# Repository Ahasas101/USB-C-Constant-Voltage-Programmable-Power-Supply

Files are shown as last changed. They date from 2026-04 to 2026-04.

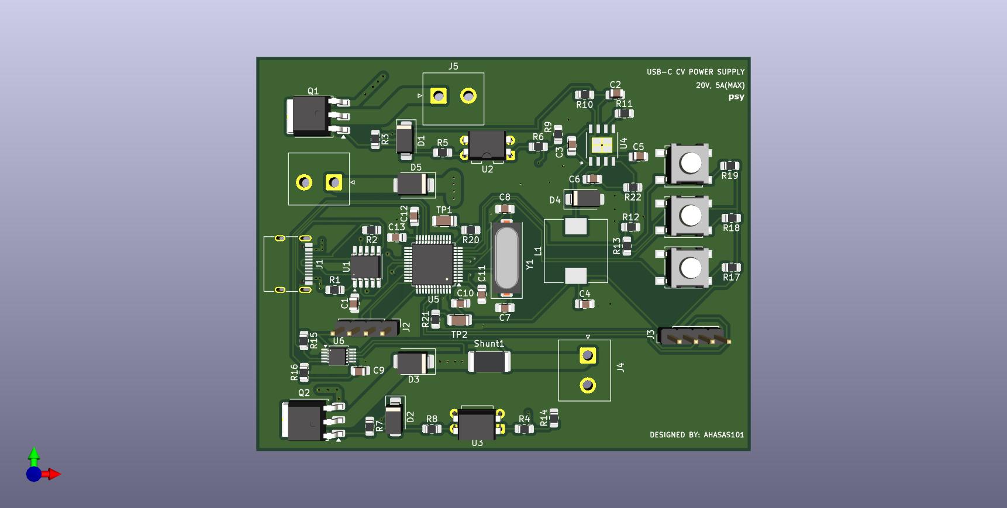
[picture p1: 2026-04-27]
Firmware/usb_ps_1/usb_ps_1.jpg

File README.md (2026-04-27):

Demonstration Video: https://www.youtube.com/shorts/JLkv3YMJE9I

100 W USB-C Power Delivery Based Programmable DC Power Supply
Overview

This project implements a compact, programmable DC power supply using USB-C Power Delivery (USB-PD). It negotiates multiple voltage levels from a USB-C charger and provides a regulated, adjustable DC output suitable for electronics development and testing.

The system is built using an STM32 microcontroller, a dedicated USB-PD controller, and a high-efficiency power conversion stage. It also includes an OLED display for real-time system feedback. Both hardware and firmware are developed from scratch .

Features
USB-C Power Delivery voltage negotiation (5V, 9V, 12V, 15V, 20V)
Programmable DC output
Dual operating modes:
Direct PD Mode (fixed voltage selection)
Adjustable Output Mode (via buck converter)
Real-time voltage and current monitoring
OLED display for live system parameters
High-efficiency power conversion
Compact and portable design
Custom PCB designed in KiCad
System Architecture
Power Path

USB-C Charger → PD Controller → Power ORing → Buck Converter → Output

Control and Monitoring

Microcontroller → INA226 Sensor → OLED Display → System Monitoring and Protection

The system architecture and block diagram are described in the project document (page 4) .

Hardware Components
STM32F030C8T6 Microcontroller
CH224K USB-PD Controller
INA226 Voltage and Current Monitor
MP1584EN Buck Converter
PMOS-based Power ORing Circuit
OLED Display (I2C)
Working Modes
1. Direct PD Mode

The PD controller negotiates and outputs fixed voltage levels directly from the USB-C charger.

2. Adjustable Output Mode

The negotiated voltage is fed into a buck converter to generate a variable DC output.

PCB Design
Designed using KiCad
Includes power stage, control circuitry, sensing modules, and display interface
High-current routing and thermal considerations implemented

Author

Ahasas Yadav

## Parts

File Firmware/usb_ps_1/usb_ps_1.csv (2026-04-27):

Reference | Qty | Value | DNP | Exclude from BOM | Exclude from Board | Footprint | Datasheet
C1 | 1 | 1uF |  |  |  | Capacitor_SMD:C_0805_2012Metric_Pad1.18x1.45mm_HandSolder | ~
C2 | 1 | 10uf |  |  |  | Capacitor_SMD:C_0805_2012Metric_Pad1.18x1.45mm_HandSolder | ~
C3 | 1 | 100nf |  |  |  | Capacitor_SMD:C_0805_2012Metric_Pad1.18x1.45mm_HandSolder | ~
C4 | 1 | 22uf |  |  |  | Capacitor_SMD:C_0805_2012Metric_Pad1.18x1.45mm_HandSolder | ~
C5 | 1 | NS |  |  |  | Capacitor_SMD:C_0805_2012Metric_Pad1.18x1.45mm_HandSolder | ~
C6 | 1 | 220pf |  |  |  | Capacitor_SMD:C_0805_2012Metric_Pad1.18x1.45mm_HandSolder | ~
C7,C8 | 2 | 18pf |  |  |  | Capacitor_SMD:C_0805_2012Metric_Pad1.18x1.45mm_HandSolder | ~
C9,C10,C11,C12,C13 | 5 | 0.1uf |  |  |  | Capacitor_SMD:C_0805_2012Metric_Pad1.18x1.45mm_HandSolder | ~
D1,D2 | 2 | 12V |  |  |  | Diode_SMD:D_SMA | ~
D3,D5 | 2 | SS10100B |  |  |  | Diode_SMD:D_SMB | ~
D4 | 1 | SS34 |  |  |  | Diode_SMD:D_SMA | ~
J1 | 1 | USB_C_Receptacle_USB2.0_16P |  |  |  | Connector_USB:USB_C_Receptacle_G-Switch_GT-USB-7010ASV | https://www.usb.org/sites/default/files/documents/usb_type-c.zip
J2 | 1 | SWD |  |  |  | Connector_PinHeader_2.54mm:PinHeader_1x04_P2.54mm_Vertical | ~
J3 | 1 | OLED |  |  |  | Connector_PinHeader_2.54mm:PinHeader_1x04_P2.54mm_Vertical | ~
J4 | 1 | O/P |  |  |  | Connector_JST:JST_NV_B02P-NV_1x02_P5.00mm_Vertical | ~
J5 | 1 | Bout |  |  |  | Connector_JST:JST_NV_B02P-NV_1x02_P5.00mm_Vertical | ~
J6 | 1 | Bin |  |  |  | Connector_JST:JST_NV_B02P-NV_1x02_P5.00mm_Vertical | ~
L1 | 1 | 10uH |  |  |  | Inductor_SMD:L_10.4x10.4_H4.8 | ~
Q1,Q2 | 2 | Q_PMOS_GDS |  |  |  | Package_TO_SOT_SMD:TO-252-3_TabPin2 | ~
R1 | 1 | 1K |  |  |  | Resistor_SMD:R_0805_2012Metric_Pad1.20x1.40mm_HandSolder | ~
R2,R20,R21 | 3 | 10K |  |  |  | Resistor_SMD:R_0805_2012Metric_Pad1.20x1.40mm_HandSolder | ~
R3,R7,R10 | 3 | 100K |  |  |  | Resistor_SMD:R_0805_2012Metric_Pad1.20x1.40mm_HandSolder | ~
R4,R6 | 2 | 470 |  |  |  | Resistor_SMD:R_0805_2012Metric_Pad1.20x1.40mm_HandSolder | ~
R5,R8 | 2 | 150 |  |  |  | Resistor_SMD:R_0805_2012Metric_Pad1.20x1.40mm_HandSolder | ~
R9,R14 | 2 | 47K |  |  |  | Resistor_SMD:R_0805_2012Metric_Pad1.20x1.40mm_HandSolder | ~
R11 | 1 | 200K |  |  |  | Resistor_SMD:R_0805_2012Metric_Pad1.20x1.40mm_HandSolder | ~
R12 | 1 | 40.2K |  |  |  | Resistor_SMD:R_0805_2012Metric_Pad1.20x1.40mm_HandSolder | ~
R13 | 1 | 124K |  |  |  | Resistor_SMD:R_0805_2012Metric_Pad1.20x1.40mm_HandSolder | ~
R15,R16,R17,R18,R19 | 5 | 4.7K |  |  |  | Resistor_SMD:R_0805_2012Metric_Pad1.20x1.40mm_HandSolder | ~
R22 | 1 | 68.1K |  |  |  | Resistor_SMD:R_0805_2012Metric_Pad1.20x1.40mm_HandSolder | ~
Shunt1 | 1 | 0.01 |  |  |  | Resistor_SMD:R_2512_6332Metric | ~
SW1 | 1 | OnOff |  |  |  | Button_Switch_SMD:SW_SPST_B3S-1000 | ~
SW2 | 1 | Mode |  |  |  | Button_Switch_SMD:SW_SPST_B3S-1000 | ~
SW3 | 1 | Level |  |  |  | Button_Switch_SMD:SW_SPST_B3S-1000 | ~
TP1 | 1 | Rst |  |  |  | Capacitor_SMD:C_1206_3216Metric | ~
TP2 | 1 | Boot |  |  |  | Capacitor_SMD:C_1206_3216Metric | ~
U1 | 1 | CH224K |  |  |  | Package_SO:SSOP-10-1EP_3.9x4.9mm_P1mm_EP2.1x3.3mm | https://www.wch.cn/downloads/file/301.html
U2,U3 | 2 | EL817 |  |  |  | Package_DIP:DIP-4_W7.62mm | http://www.everlight.com/file/ProductFile/EL817.pdf
U4 | 1 | MP1584EN-LF-P |  |  |  | footprints:SOIC8E_MPS_MNP | https://www.monolithicpower.com/en/documentview/productdocument/index/version/2/document_type/Datasheet/lang/en/sku/MP1584EN-LF-Z
U5 | 1 | STM32F030C8Tx |  |  |  | Package_QFP:LQFP-48_7x7mm_P0.5mm | https://www.st.com/resource/en/datasheet/stm32f030c8.pdf
U6 | 1 | INA226 |  |  |  | Package_SO:VSSOP-10_3x3mm_P0.5mm | http://www.ti.com/lit/ds/symlink/ina226.pdf
Y1 | 1 | 8MHz |  |  |  | Crystal:Crystal_SMD_HC49-SD | ~

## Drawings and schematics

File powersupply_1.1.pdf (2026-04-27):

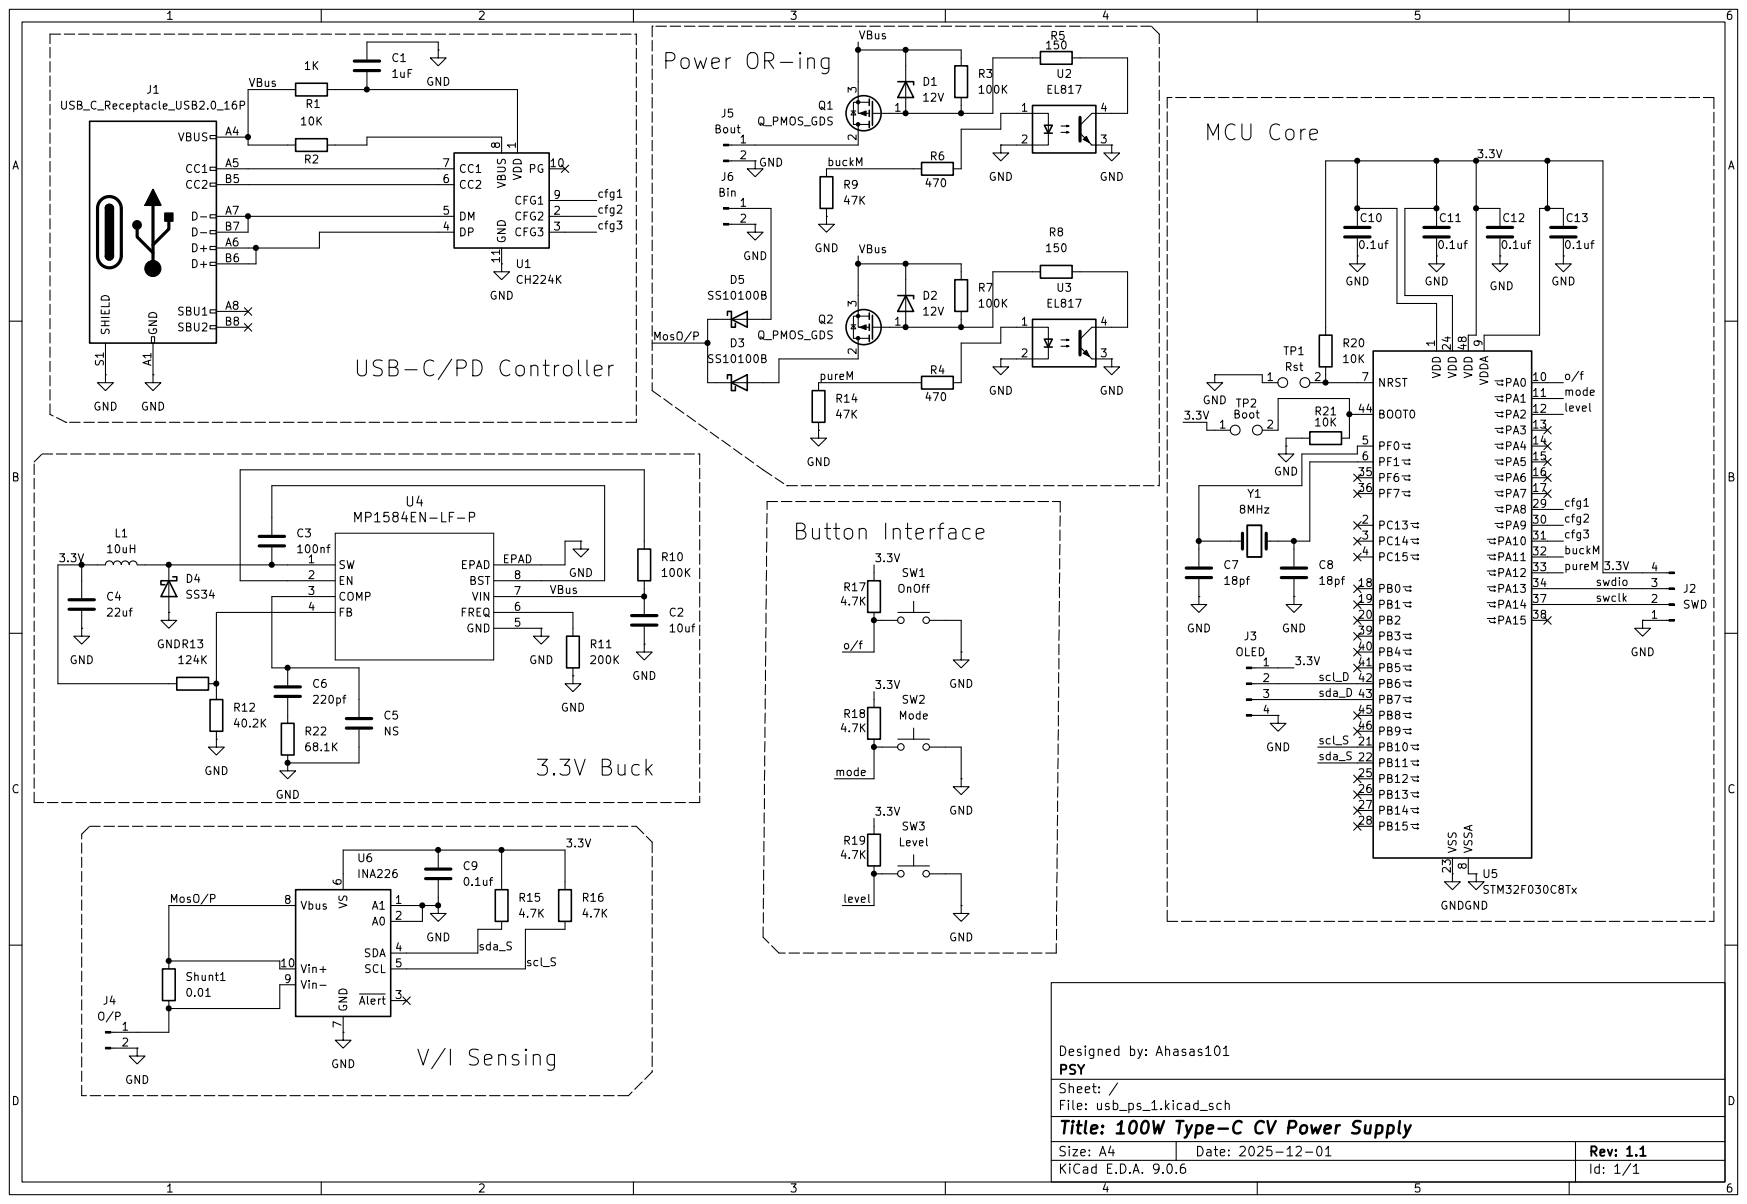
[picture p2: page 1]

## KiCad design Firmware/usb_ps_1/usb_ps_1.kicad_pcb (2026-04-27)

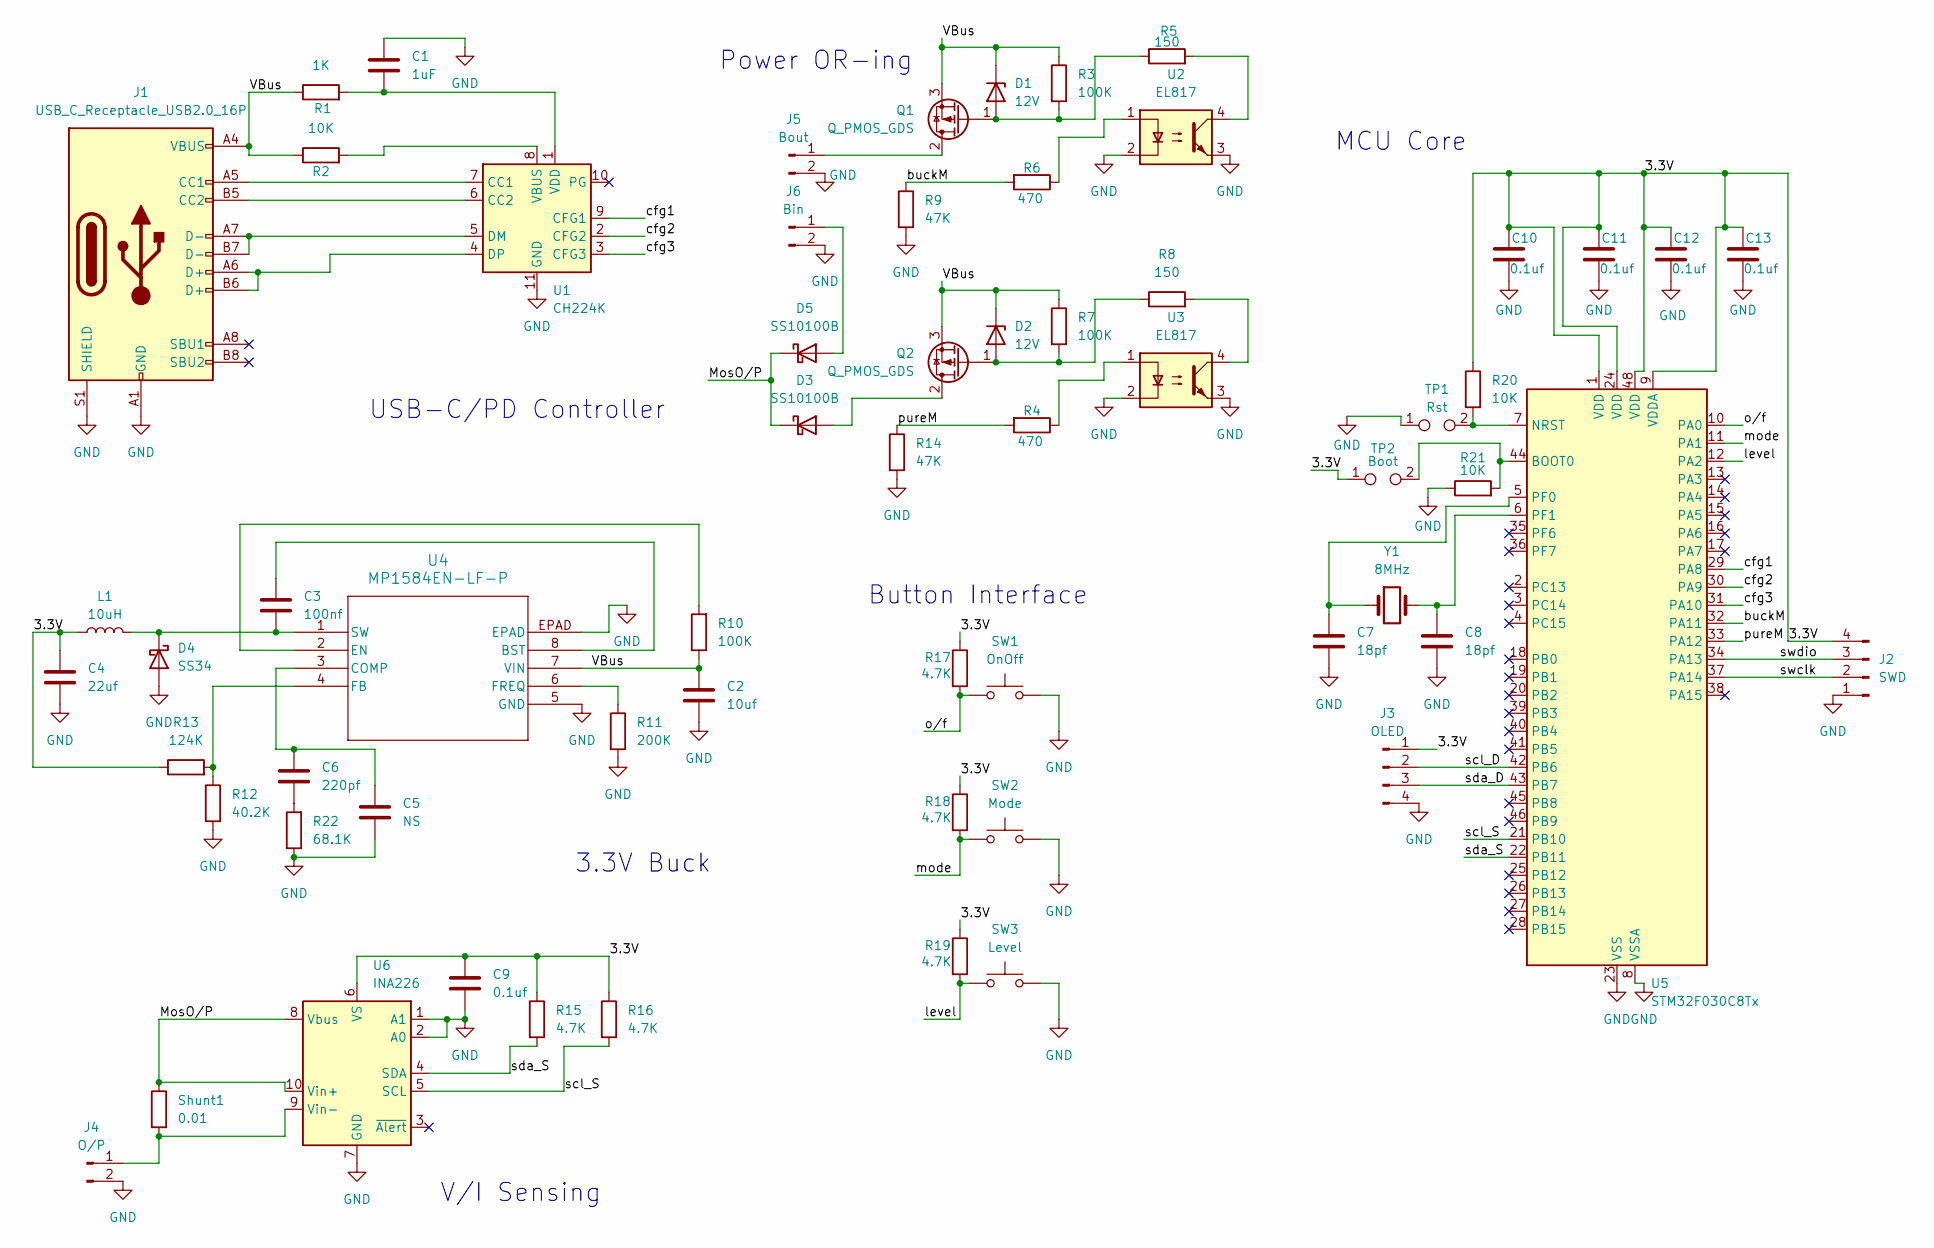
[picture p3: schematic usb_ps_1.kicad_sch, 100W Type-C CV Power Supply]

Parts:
C1: 1uF; C_0805_2012Metric_Pad1.18x1.45mm_HandSolder
C2: 10uf; C_0805_2012Metric_Pad1.18x1.45mm_HandSolder
C3: 100nf; C_0805_2012Metric_Pad1.18x1.45mm_HandSolder
C4: 22uf; C_0805_2012Metric_Pad1.18x1.45mm_HandSolder
C5: NS; C_0805_2012Metric_Pad1.18x1.45mm_HandSolder
C6: 220pf; C_0805_2012Metric_Pad1.18x1.45mm_HandSolder
C7, C8: 18pf; C_0805_2012Metric_Pad1.18x1.45mm_HandSolder
C9, C10, C11, C12, C13: 0.1uf; C_0805_2012Metric_Pad1.18x1.45mm_HandSolder
D1, D2: 12V; D_SMA
D3, D5: SS10100B; D_SMB
D4: SS34; D_SMA
J1: USB_C_Receptacle_USB2.0_16P; USB_C_Receptacle_G-Switch_GT-USB-7010ASV
J2: SWD; PinHeader_1x04_P2.54mm_Vertical
J3: OLED; PinHeader_1x04_P2.54mm_Vertical
J4: O/P; JST_NV_B02P-NV_1x02_P5.00mm_Vertical
J5: Bout; JST_NV_B02P-NV_1x02_P5.00mm_Vertical
J6: Bin; JST_NV_B02P-NV_1x02_P5.00mm_Vertical
L1: 10uH; L_10.4x10.4_H4.8
Q1, Q2: Q_PMOS_GDS; TO-252-3_TabPin2
R1: 1K; R_0805_2012Metric_Pad1.20x1.40mm_HandSolder
R2, R20, R21: 10K; R_0805_2012Metric_Pad1.20x1.40mm_HandSolder
R3, R7, R10: 100K; R_0805_2012Metric_Pad1.20x1.40mm_HandSolder
R4, R6: 470; R_0805_2012Metric_Pad1.20x1.40mm_HandSolder
R5, R8: 150; R_0805_2012Metric_Pad1.20x1.40mm_HandSolder
R9, R14: 47K; R_0805_2012Metric_Pad1.20x1.40mm_HandSolder
R11: 200K; R_0805_2012Metric_Pad1.20x1.40mm_HandSolder
R12: 40.2K; R_0805_2012Metric_Pad1.20x1.40mm_HandSolder
R13: 124K; R_0805_2012Metric_Pad1.20x1.40mm_HandSolder
R15, R16, R17, R18, R19: 4.7K; R_0805_2012Metric_Pad1.20x1.40mm_HandSolder
R22: 68.1K; R_0805_2012Metric_Pad1.20x1.40mm_HandSolder
SW1: OnOff; SW_SPST_B3S-1000
SW2: Mode; SW_SPST_B3S-1000
SW3: Level; SW_SPST_B3S-1000
Shunt1: 0.01; R_2512_6332Metric
TP1: Rst; C_1206_3216Metric
TP2: Boot; C_1206_3216Metric
U1: CH224K; SSOP-10-1EP_3.9x4.9mm_P1mm_EP2.1x3.3mm
U2, U3: EL817; DIP-4_W7.62mm
U4: MP1584EN-LF-P; SOIC8E_MPS_MNP
U5: STM32F030C8Tx; LQFP-48_7x7mm_P0.5mm
U6: INA226; VSSOP-10_3x3mm_P0.5mm
Y1: 8MHz; Crystal_SMD_HC49-SD

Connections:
/3.3V: C4.1, C9.1, C10.1, C11.1, C12.1, C13.1, J2.4, J3.1, L1.1, R13.1, R15.1, R16.1, R17.1, R18.1, R19.1, R20.1, TP2.1, U5.1 (VDD), U5.9 (VDDA), U5.24 (VDD), U5.48 (VDD), U6.6 (VS)
/MosO/P: D3.1 (K), D5.1 (K), Shunt1.1, U6.8 (Vbus), U6.10 (Vin+)
/VBus: C2.1, D1.1 (K), D2.1 (K), J1.A4 (VBUS), J1.A9 (VBUS), J1.B4 (VBUS), J1.B9 (VBUS), Q1.3 (S), Q2.3 (S), R1.1, R2.1, R3.1, R7.1, R10.1, U4.7 (VIN)
/buckM: R6.2, R9.1, U5.32 (PA11)
/cfg1: U1.9 (CFG1), U5.29 (PA8)
/cfg2: U1.2 (CFG2), U5.30 (PA9)
/cfg3: U1.3 (CFG3), U5.31 (PA10)
/level: R19.2, SW3.1, U5.12 (PA2)
/mode: R18.2, SW2.1, U5.11 (PA1)
/o/f: R17.2, SW1.1, U5.10 (PA0)
/pureM: R4.2, R14.1, U5.33 (PA12)
/scl_D: J3.2, U5.42 (PB6)
/scl_S: R16.2, U5.21 (PB10), U6.5 (SCL)
/sda_D: J3.3, U5.43 (PB7)
/sda_S: R15.2, U5.22 (PB11), U6.4 (SDA)
/swclk: J2.2, U5.37 (PA14)
/swdio: J2.3, U5.34 (PA13)
GND: C1.1, C2.2, C4.2, C5.2, C7.2, C8.2, C9.2, C10.2, C11.2, C12.2, C13.2, D4.2 (A), J1.A1 (GND), J1.A12 (GND), J1.B1 (GND), J1.B12 (GND), J1.S1 (SHIELD), J2.1, J3.4, J4.2, J5.2, J6.2, R9.2, R11.2, R12.2, R14.2, R21.1, R22.1, SW1.2, SW2.2, SW3.2, TP1.1, U1.11 (GND), U2.2, U2.3, U3.2, U3.3, U4.5 (GND), U4.EPAD, U5.8 (VSSA), U5.23 (VSS), U5.47 (VSS), U6.1 (A1), U6.2 (A0), U6.7 (GND)
unnamed: C6.2, R22.2
unnamed: D1.2 (A), Q1.1 (G), R3.2, R5.1
unnamed: D2.2 (A), Q2.1 (G), R7.2, R8.1
unnamed: D3.2 (A), Q2.2 (D)
unnamed: C3.2, D4.1 (K), L1.2, U4.1 (SW)
unnamed: D5.2 (A), J6.1
unnamed: J1.A5 (CC1), U1.7 (CC1)
unnamed: J1.B5 (CC2), U1.6 (CC2)
unnamed: J4.1, Shunt1.2, U6.9 (Vin-)
unnamed: J5.1, Q1.2 (D)
unnamed: R4.1, U3.1
unnamed: R5.2, U2.4
unnamed: R6.1, U2.1
unnamed: R8.2, U3.4
unnamed: J1.A7 (D-), J1.B7 (D-), U1.5 (DM)
unnamed: J1.A6 (D+), J1.B6 (D+), U1.4 (DP)
unnamed: R2.2, U1.8 (VBUS)
unnamed: C1.2, R1.2, U1.1 (VDD)
unnamed: C3.1, U4.8 (BST)
unnamed: C5.1, C6.1, U4.3 (COMP)
unnamed: R10.2, U4.2 (EN)
unnamed: R12.1, R13.2, U4.4 (FB)
unnamed: R11.1, U4.6 (FREQ)
unnamed: R21.2, TP2.2, U5.44 (BOOT0)
unnamed: R20.2, TP1.2, U5.7 (NRST)
unnamed: C7.1, U5.5 (PF0), Y1.1
unnamed: C8.1, U5.6 (PF1), Y1.2

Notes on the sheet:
Power OR-ing
MCU Core
3.3V Buck
V/I Sensing
USB-C/PD Controller
Button Interface

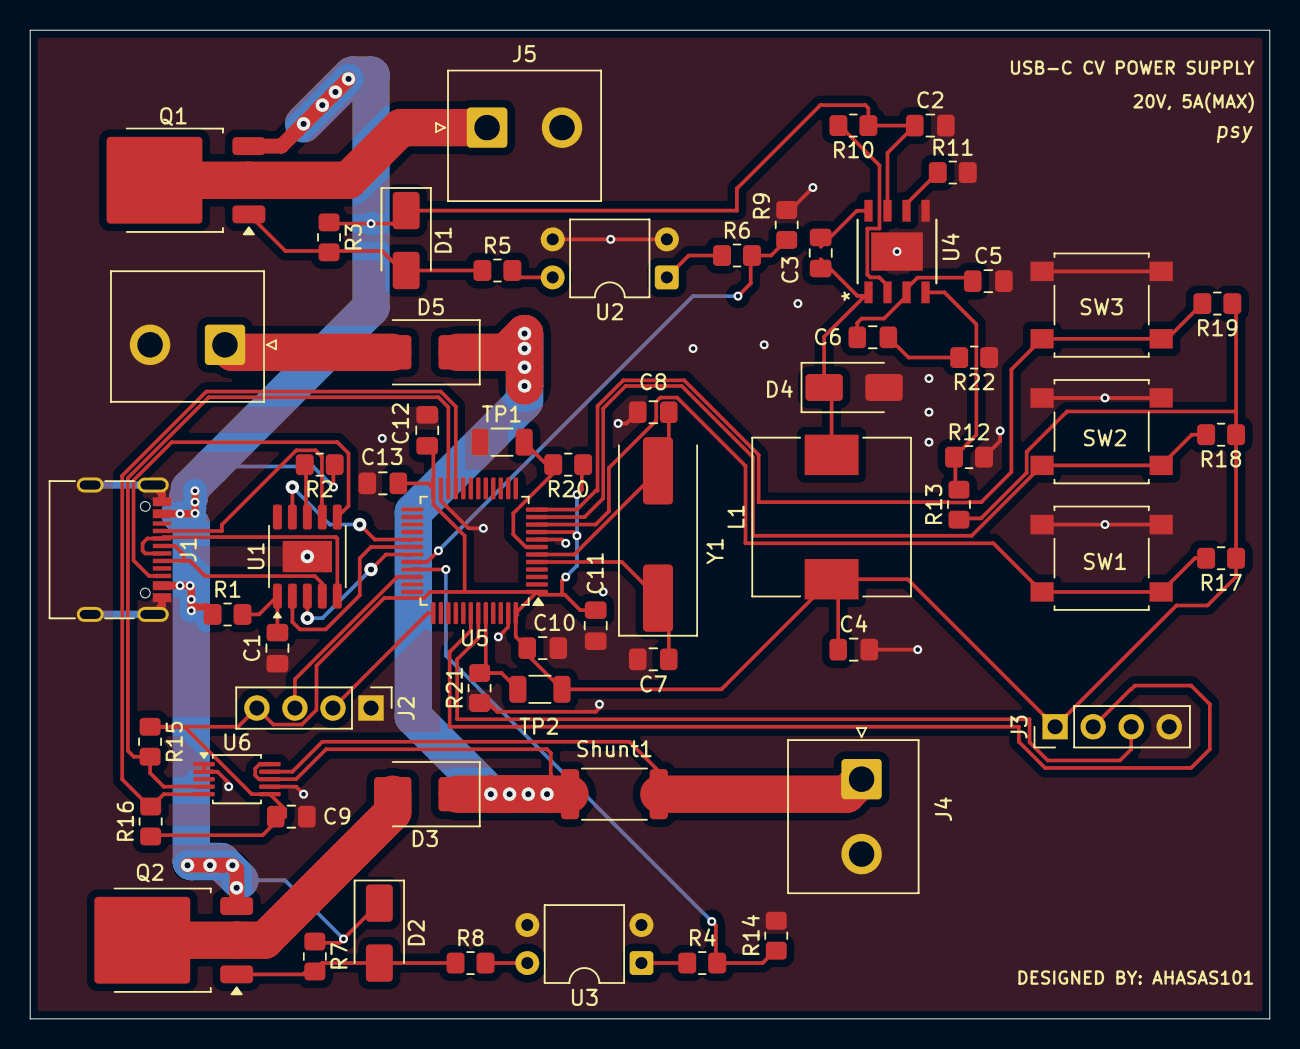
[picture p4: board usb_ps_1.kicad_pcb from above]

Board: 2 copper layers, 82.8 x 66.0 mm, 62 parts (0 on the bottom side), 45 nets.

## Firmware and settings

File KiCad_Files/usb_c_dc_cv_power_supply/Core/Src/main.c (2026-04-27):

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
/* Includes ------------------------------------------------------------------*/
#include "main.h"

/* USER CODE BEGIN Includes */
#include "oled.h"
#include "INA226.h"
#include <stdio.h>
#include <stdlib.h>
/* USER CODE END Includes */

I2C_HandleTypeDef hi2c1;
I2C_HandleTypeDef hi2c2;

/* USER CODE BEGIN PV */
volatile mode_type Mode = Mode1;
volatile voltage_level Voltage = Five;
volatile output_status Output = OutputOff;
volatile config_pins_state cfg;
volatile uint32_t prev_tick = 0;
/* USER CODE END PV */

void SystemClock_Config(void);
static void MX_GPIO_Init(void);
static void MX_I2C1_Init(void);
static void MX_I2C2_Init(void);
/* USER CODE BEGIN PFP */
static void set_pure_mosfet(uint8_t val);
static void set_buck_mosfet(uint8_t val);
static void toggle_output(void);
static void toggle_mode(void);
static void toggle_voltage_level(void);
static void set_decoy_voltage(config_pins_state* conf);

static void print_output(void);
static void print_mode(void);
static void print_voltage_current_power(void);
static void print_data(void);


/* USER CODE END PFP */

/**
  * @brief  The application entry point.
  * @retval int
  */
int main(void)
{

  /* MCU Configuration--------------------------------------------------------*/

  /* Reset of all peripherals, Initializes the Flash interface and the Systick. */
  HAL_Init();

  /* Configure the system clock */
  SystemClock_Config();

  /* Initialize all configured peripherals */
  MX_GPIO_Init();
  MX_I2C1_Init();
  MX_I2C2_Init();
  /* USER CODE BEGIN 2 */
  cfg.cfg1 = CFGSET;
  cfg.cfg2 = CFGSET;
  cfg.cfg3 = CFGSET;

  set_decoy_voltage((config_pins_state *)&cfg);

  SSD1306_Init();

  SSD1306_Clear();

  //SSD1306_Print15X(0, 0, "MODE-1");
  //SSD1306_Print15X(95, 0, "ON");

  SSD1306_Print2X(0, 0, "PSY");
  SSD1306_Print15X(0, 25, "Designed By:");
  SSD1306_Print15X(0, 45, "Ahasas101");



  //SSD1306_Print2X(0, 32, "10.234 A");
  //SSD1306_Print2X(0, 50, "35.691 W");
  SSD1306_Update();
  INA226_Init_Status status = INA226_Init();
  HAL_Delay(2000);


  /* USER CODE END 2 */

  /* Infinite loop */
  /* USER CODE BEGIN WHILE */
  while (1)
  {
    /* USER CODE END WHILE */

    /* USER CODE BEGIN 3 */
	//  print_voltage_current_power();
	//  HAL_Delay(10);
	print_data();
	HAL_Delay(10);
  }
  /* USER CODE END 3 */
}

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
/* USER CODE BEGIN 4 */

void HAL_GPIO_EXTI_Callback(uint16_t GPIO_Pin)
{

	uint32_t curr_tick = HAL_GetTick();
	if(curr_tick - prev_tick > 500)
	{
		prev_tick = HAL_GetTick();
		if(GPIO_Pin == B_1_OP_OnOff_Pin)
		{
			toggle_output();
			//print_output();
		//print_data();
		}

		else if(GPIO_Pin == B_2_VL_Pin)
		{
			set_pure_mosfet(OFF);
			set_buck_mosfet(OFF);
			Output = OutputOff;
			toggle_voltage_level();
			//print_data();


		}

		else if(GPIO_Pin == B_3_Mode_Pin)
		{
			set_pure_mosfet(OFF);
			set_buck_mosfet(OFF);
			Output = OutputOff;
			toggle_mode();
			//print_mode();
			//print_data();

		}
	}
}

static void set_pure_mosfet(uint8_t val)
{
	if(val == ON)
	{
		HAL_GPIO_WritePin(pure_mosfet_GPIO_Port, pure_mosfet_Pin, GPIO_PIN_SET);
	}
	else
	{
		HAL_GPIO_WritePin(pure_mosfet_GPIO_Port, pure_mosfet_Pin, GPIO_PIN_RESET);
	}
}

static void set_buck_mosfet(uint8_t val)
{
	if(val == ON)
	{
		HAL_GPIO_WritePin(buck_mosfet_GPIO_Port, buck_mosfet_Pin, GPIO_PIN_SET);

	}
	else
	{
		HAL_GPIO_WritePin(buck_mosfet_GPIO_Port, buck_mosfet_Pin, GPIO_PIN_RESET);
	}
}

static void toggle_output(void)
{

	switch(Output)
	{
	case OutputOff:
		Output = OutputOn;
		break;
	default:
		Output = OutputOff;
		break;
	}


	if(Output == OutputOn)
	{
		if(Mode == Mode2)
		{
			set_pure_mosfet(OFF);
			set_buck_mosfet(ON);
		}
		else
		{
			set_buck_mosfet(OFF);
			set_pure_mosfet(ON);
		}

	}
	else
	{
		set_buck_mosfet(OFF);
		set_pure_mosfet(OFF);
	}
}

static void toggle_mode(void)
{
	if(Mode == Mode1)
	{
		Mode = Mode2;
	}
	else
	{
		Mode = Mode1;
	}
}

static void toggle_voltage_level(void)
{
	switch(Voltage)
	{
	case Five:
		Voltage = Nine;
		cfg.cfg1 = CFGRESET;
		cfg.cfg2 = CFGRESET;
		cfg.cfg3 = CFGRESET;
		break;

	case Nine:
		Voltage = Twelve;
		cfg.cfg1 = CFGRESET;
		cfg.cfg2 = CFGRESET;
		cfg.cfg3 = CFGSET;
		break;

	case Twelve:
		Voltage = Fifteen;
		cfg.cfg1 = CFGRESET;
		cfg.cfg2 = CFGSET;
		cfg.cfg3 = CFGSET;
		break;

	case Fifteen:
		Voltage = Twenty;
		cfg.cfg1 = CFGRESET;
		cfg.cfg2 = CFGSET;
		cfg.cfg3 = CFGRESET;
		break;

	case Twenty:
		Voltage = Five;
		cfg.cfg1 = CFGSET;
		cfg.cfg2 = CFGSET;
		cfg.cfg3 = CFGSET;
		break;
	}
	set_decoy_voltage((config_pins_state *)&cfg);

}

static void set_decoy_voltage(config_pins_state *conf)
{
	HAL_GPIO_WritePin(cfg1_GPIO_Port, cfg1_Pin, (conf->cfg1));
	HAL_GPIO_WritePin(cfg2_GPIO_Port, cfg2_Pin, (conf->cfg2));
	HAL_GPIO_WritePin(cfg3_GPIO_Port, cfg3_Pin, (conf->cfg3));
}

static void print_data(void)
{
	SSD1306_Clear();
	char *output_pbuff;
	if(Output == OutputOn) {output_pbuff = "ON";}
	else {output_pbuff = "OFF";}
	SSD1306_Print15X(95, 0, output_pbuff);

	char *mode_pbuff;
	if(Mode == Mode1) {mode_pbuff = "MODE1";}
	else if(Mode == Mode2) {mode_pbuff = "Mode2";}
	SSD1306_Print15X(0, 0, mode_pbuff);

	char vbuff[16];
	char cbuff[16];
	char powbuff[16];
	float voltage = INA226_ReadBusVoltage();

	float current = (INA226_ReadCurrent());

	float power   = (INA226_ReadPower());

	sprintf(vbuff, "%.4f V", voltage);
	sprintf(cbuff, "%.4f A", current);
	sprintf(powbuff, "%.4f W", power);
	SSD1306_Print2X(0, 14, vbuff);
	SSD1306_Print2X(0, 32, cbuff);
	SSD1306_Print2X(0, 50, powbuff);
	SSD1306_Update();

}

static void print_output(void)
{
	char *output_pbuff;
	if(Output == OutputOn) output_pbuff = "ON"; output_pbuff = "OFF";
	SSD1306_Print15X(95, 0, output_pbuff);
	SSD1306_Update();
}

static void print_mode(void)
{
	char *mode_pbuff;
	if(Mode == Mode1) {mode_pbuff = "MODE1";}
	else if(Mode == Mode2) {mode_pbuff = "Mode2";}
	SSD1306_Print15X(0, 0, mode_pbuff);
	SSD1306_Update();
}

static void print_voltage_current_power(void)
{
	char vbuff[16];
	char cbuff[16];
	char powbuff[16];
	INA226_Init();
	float voltage = INA226_ReadBusVoltage();
	float current = INA226_ReadCurrent();
	float power   = INA226_ReadPower();

	sprintf(vbuff, "%.3f V", voltage);
	sprintf(cbuff, "%.3f A", current);
	sprintf(powbuff,"%.3f W", power);
	SSD1306_Print2X(0, 14, vbuff);
	SSD1306_Print2X(0, 32, vbuff);
	SSD1306_Print2X(0, 50, powbuff);
	SSD1306_Update();
}



/* USER CODE END 4 */
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


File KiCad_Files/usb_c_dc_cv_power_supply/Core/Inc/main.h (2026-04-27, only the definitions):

#define B_1_OP_OnOff_Pin GPIO_PIN_0
#define B_1_OP_OnOff_GPIO_Port GPIOA
#define B_1_OP_OnOff_EXTI_IRQn EXTI0_1_IRQn
#define B_3_Mode_Pin GPIO_PIN_1
#define B_3_Mode_GPIO_Port GPIOA
#define B_3_Mode_EXTI_IRQn EXTI0_1_IRQn
#define B_2_VL_Pin GPIO_PIN_2
#define B_2_VL_GPIO_Port GPIOA
#define B_2_VL_EXTI_IRQn EXTI2_3_IRQn
#define cfg1_Pin GPIO_PIN_8
#define cfg1_GPIO_Port GPIOA
#define cfg2_Pin GPIO_PIN_9
#define cfg2_GPIO_Port GPIOA
#define cfg3_Pin GPIO_PIN_10
#define cfg3_GPIO_Port GPIOA
#define buck_mosfet_Pin GPIO_PIN_11
#define buck_mosfet_GPIO_Port GPIOA
#define pure_mosfet_Pin GPIO_PIN_12
#define pure_mosfet_GPIO_Port GPIOA
#define ON		1
#define OFF		0

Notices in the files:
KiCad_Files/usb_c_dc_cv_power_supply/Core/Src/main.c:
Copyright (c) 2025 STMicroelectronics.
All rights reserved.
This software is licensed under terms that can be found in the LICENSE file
